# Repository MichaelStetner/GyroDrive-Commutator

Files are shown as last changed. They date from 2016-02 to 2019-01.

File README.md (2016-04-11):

# GyroDrive-Commutator
GyroDrive-Commutator-Adaptor

## Pinout for X2
Oriented with X1 up and X2 down

| | | | | | | | |
|---|---|---|---|---|---|---|---|
|  CHAN2  |  CHAN3  |  ICOM | IX |  AGND*  |  CHAN4  |  DGND^  | SCL |
|  CHAN1  | STIMOUT | STIMIN  | V- | V+ |  AGND*  |  DGND^  | SDA |

\*Shorted to each other on board

^Shorted to each other on board

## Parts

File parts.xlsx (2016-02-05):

Name | Quantity | Purpose | Description | Manufacturer | Part Number | Link | Digikey cart | http://www.digikey.com/short/3t4q8m
C1-C2 | 2 | Bypass capacitor for voltage regulator input | 0402, Ceramic, X7R, 0.1uF, 10%, 25V | Murata Electronics | GRM155R71E104KE14D | http://www.digikey.com/short/3t3qcf
C3-C4 | 2 | Bypass capacitor for voltage regulator output | 0402, Ceramic, X5R, 0.47uF, 10%, 6.3V | Murata Electronics | GRM155R60J474KE19D | http://www.digikey.com/short/3t3q8z
C5-C6 | 2 | Bypass capacitor for instrumation amplifier | 0805, Ceramic, X7R, 100nF, 10%, 25V | Murata Electronics | GRM21BR71E104KA01L | http://www.digikey.com/short/3t4797
R1 | 1 | Current limiting resistor for hall sensor | 0805, 10k, 1%, 1/8W | ROHM Semiconductor | MCR10ERTF1002 | http://www.digikey.com/short/3t4tc5
R2-R5 | 4 | Voltage divider for electrode signals (with R6-R9) | 0805, 357k, 1%, 1/8W | ROHM Semiconductor | MCR10ERTF3573 | http://www.digikey.com/short/3t475h
R6-R9 | 4 | Voltage divider for electrode signals (with R2-R5) | 0805, 3.6k, 1%, 1/8W | ROHM Semiconductor | MCR10ERTF3601 | http://www.digikey.com/short/3t4t7z
U1 | 1 | Hall sensor |  | Lake Shore Cryonics | HGT-2101-10 | http://www.lakeshore.com/products/Hall-Magnetic-Sensors/Pages/Ordering.aspx
U2 | 1 | I2C level translating repeater | PCA9517 | NXP Semiconductors | PCA9517D,118 | http://www.digikey.com/short/3t4t2n
U3 | 1 | Voltage regulator, 5V | TPS715 fixed | Texas Instruments | TPS71550DCKR | http://www.digikey.com/short/3t4td1
U4 | 1 | Voltage regulator, 2.5V | TPS715 fixed | Texas Instruments | TPS71525DCKR | http://www.digikey.com/short/3t4tv1
U5-U7 | 3 | Instrumentation amplifier | INA2141U | Texas Instruments | INA2141U | http://www.digikey.com/short/3t4tt7
X1 | 1 | Connector to commutator | DB-25 Connector, male | Norcomp Inc | 190-25MA-ND | http://www.digikey.com/short/3t47vd
X2 | 1 | Connector to bird | 16-pin header, male | Amphenol FCI | 68602-116HLF | http://www.digikey.com/short/3t43d1
X2 | 1 | Connector to bird | 16-pin header, female | TE Connectivity | 1658620-3 | http://www.digikey.com/short/3t430r

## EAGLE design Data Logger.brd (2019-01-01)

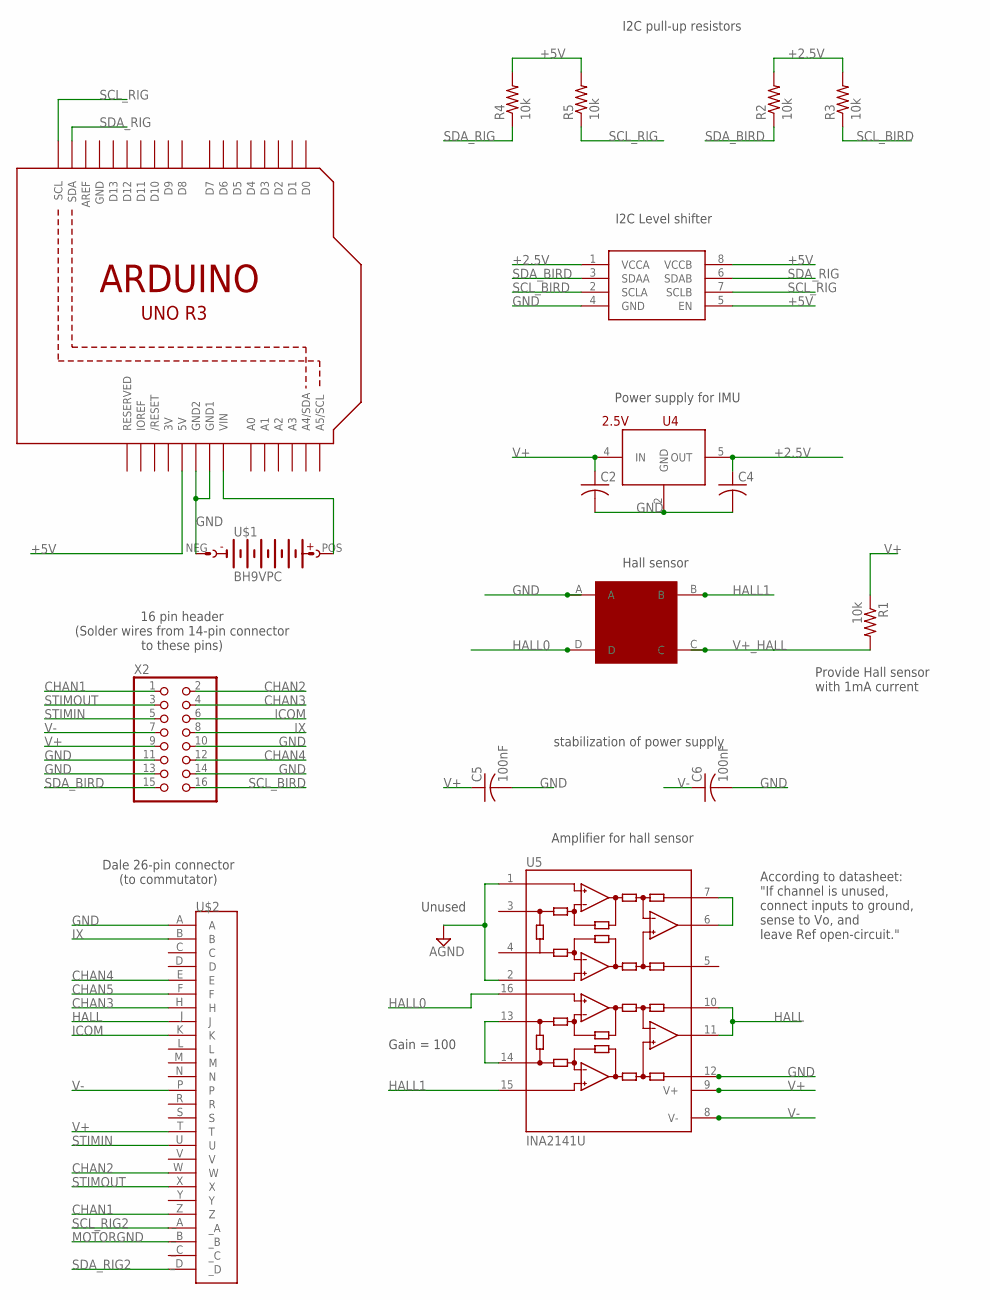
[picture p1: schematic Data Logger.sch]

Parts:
C2, C4: C-USC0402; C0402
C5, C6: 100nF; C0805
R1: 10k; R0805
R2, R3, R4, R5: 10k; R0402
U1: HALL; HALL_ON_SIDE
U2: PCA9517; SO-08
U4: 2.5V; SC70
U5: INA2141U; SO16-1
U6: ARDUINOR3-DIMENSION; ARDUINOR3
U$1: BH9VPC
U$2: MMD1P22G-26-M101
X2: PINHD-2X8; 2X08

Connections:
3V: U6.3V
+2.5V: C4.1, R2.2, R3.2, U2.1 (VCCA), U4.5 (OUT)
+5V: R4.2, R5.2, U2.5 (EN), U2.8 (VCCB), U6.5V
+9V: U6.VIN, U$1.POS
CHAN1: U$2.Z, X2.1
CHAN2: U$2.W, X2.2
CHAN3: U$2.H, X2.4
CHAN4: U$2.E, X2.12
CHAN5: U$2.F
GND: C2.2, C4.2, C5.2, C6.2, U1.A, U2.4 (GND), U4.2 (GND), U5.1 (INA-), U5.2 (INA+), U5.12 (REFB), U6.GND, U6.GND1, U6.GND2, U$1.NEG, U$2.A, X2.10, X2.11, X2.13, X2.14
HALL: U5.10 (SENSEB), U5.11 (VOB), U$2.J
HALL0: U1.D, U5.16 (INB-)
HALL1: U1.B, U5.15 (INB+)
ICOM: U$2.K, X2.6
IX: U$2.B, X2.8
MOTORGND: U$2._B
unnamed: U5.13 (JB), U5.14 (JB)
SCL_BIRD: R3.1, U2.2 (SCLA), X2.16
SCL_RIG: R5.1, U2.7 (SCLB), U6.SCL
SCL_RIG2: U$2._A
SDA_BIRD: R2.1, U2.3 (SDAA), X2.15
SDA_RIG: R4.1, U2.6 (SDAB), U6.SDA
SDA_RIG2: U$2._D
STIMIN: U$2.U, X2.5
STIMOUT: U$2.X, X2.3
UNUSED: U5.6 (VOA), U5.7 (SENSEA)
V+: C2.1, C5.1, R1.1, U4.4 (IN), U5.9 (V+), U$2.T, X2.9
V+_HALL: R1.2, U1.C
V-: C6.1, U5.8 (V-), U$2.P, X2.7

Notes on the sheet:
stabilization of power supply
Hall sensor
Amplifier for hall sensor
Gain = 100
Unused
Provide Hall sensor with 1mA current
16 pin header (Solder wires from 14-pin connector to these pins)
According to datasheet: "If channel is unused, connect inputs to ground, sense to Vo, and leave Ref open-circuit."
I2C pull-up resistors
Dale 26-pin connector (to commutator)
I2C Level shifter
Power supply for IMU

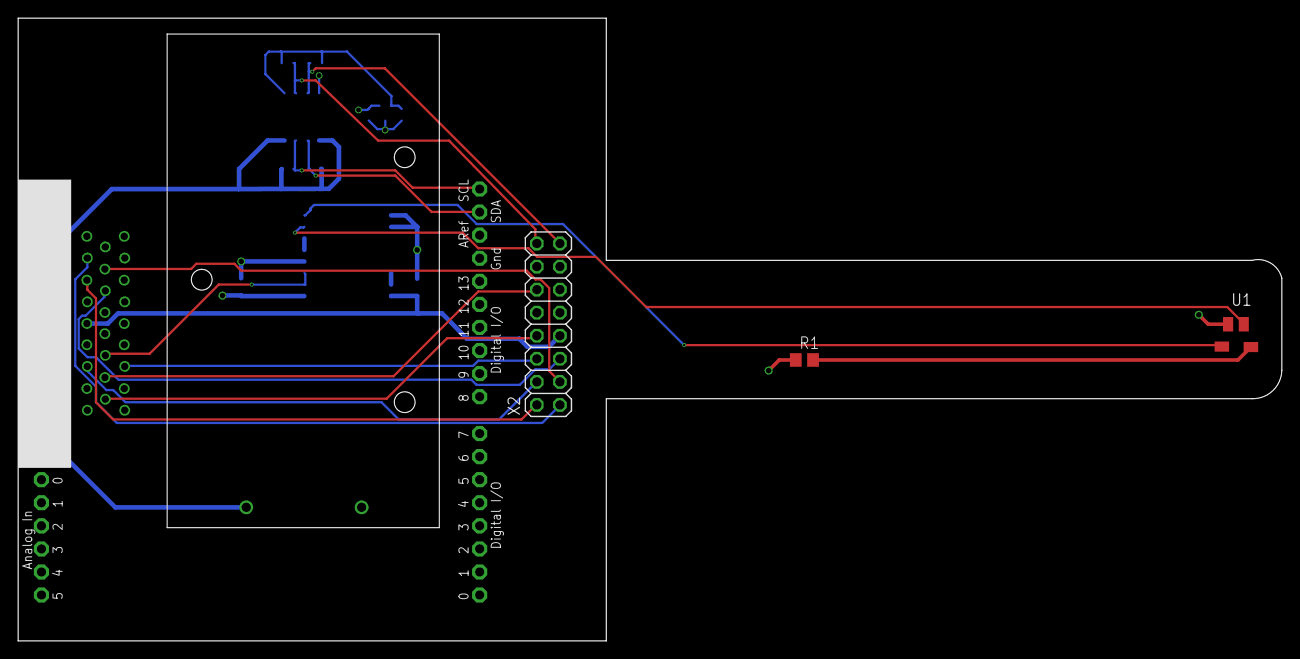
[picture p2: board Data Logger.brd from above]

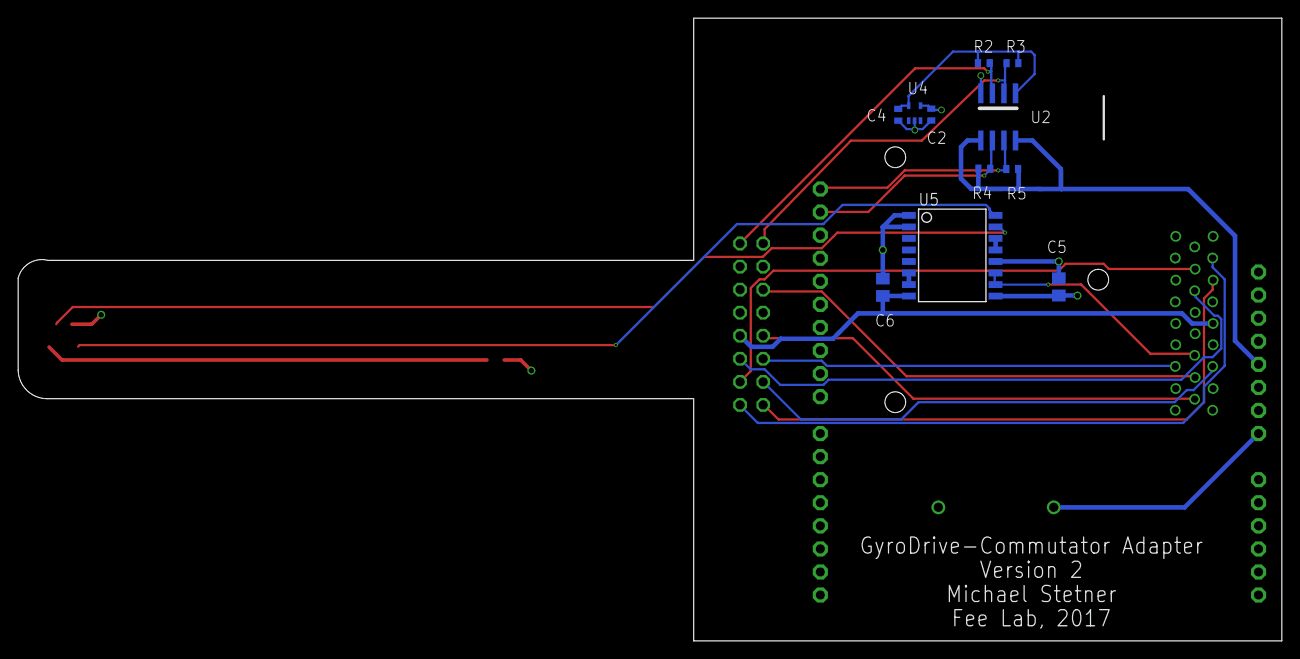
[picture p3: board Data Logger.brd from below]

Board: 4 copper layers, 139.2 x 68.6 mm, 17 parts (11 on the bottom side), 24 nets.

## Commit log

2016-02-03 Added 5ch pre-amp from Tatuso. This will be the basis of my designs.
    [GyroDrive-Commutator-Adaptor.brd, GyroDrive-Commutator-Adaptor.sch]
2016-02-03 Removed VGROUND and changed JMP1 pinout
    [GyroDrive-Commutator-Adaptor.brd, GyroDrive-Commutator-Adaptor.sch]
2016-02-03 Made board into 4 layers. Put in resistors for voltage dividers
    [GyroDrive-Commutator-Adaptor.brd, GyroDrive-Commutator-Adaptor.sch]
2016-02-04 Finished routing
    [GyroDrive-Commutator-Adaptor.brd, GyroDrive-Commutator-Adaptor.sch]
2016-02-05 added parts list
    [GyroDrive-Commutator-Adaptor.brd, GyroDrive-Commutator-Adaptor.sch, parts.xlsx]
2016-02-05 Shortened board by 0.75 inches to make room for DB25-Dale adapter
    [GyroDrive-Commutator-Adaptor.brd]
2016-02-06 I2C pull-up resistors added
    [GyroDrive-Commutator-Adaptor.brd, GyroDrive-Commutator-Adaptor.sch]
2016-02-06 Fixed stop mask DRC errors on some resistors and capacitors
    [GyroDrive-Commutator-Adaptor.brd, GyroDrive-Commutator-Adaptor.sch]
2016-02-08 Removed instrumentation amplifiers for electrodes
    [GyroDrive-Commutator-Adaptor.brd, GyroDrive-Commutator-Adaptor.sch]
2016-02-09 narrower board - removed empty space
    [GyroDrive-Commutator-Adaptor.brd]
2016-03-18 Added orientation marker for PCA9517 to silkscreen
    [GyroDrive-Commutator-Adaptor.brd]
2017-02-09 redesign as an arduino shield
    [GyroDrive-Commutator-Adaptor.brd, GyroDrive-Commutator-Adaptor.sch]
2017-02-24 Add orientation marker for U2
    [GyroDrive-Commutator-Adaptor.brd]
2019-01-01 schematic and layout formatting for thesis
    [Data Logger.brd, Data Logger.sch]
